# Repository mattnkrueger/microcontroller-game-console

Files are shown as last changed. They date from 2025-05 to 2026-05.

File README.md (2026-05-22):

# Micro-controller Gaming Console

### Description
Microcontroller gaming console featuring "Etch-E-Sketch" and pixel art applications. Custom 3D Printed model housing 64x64 LED panel driven by ESP32, and 12 peripheral inputs morintored by Arduino Uno. 

---

### Repository Tags
<div align="left">
  Uiowa
  Handwritten
  Arduino
  ESP
  ESP
  Pio
  Fusion360
  Bambu Studio
</div>

---

<p align="center">
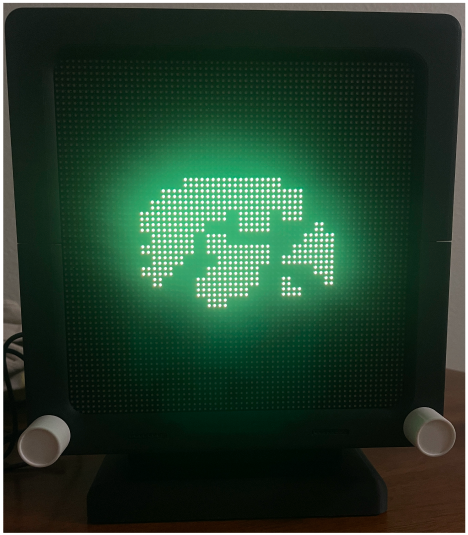
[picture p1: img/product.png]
display
  
</p>

Our project goal was to build something that wont be thrown away - or stripped down to preserve parts - after the class ends. The LED Matrix (and game system) sufficed; it allows for various programs, unique displays, and extendability beyond this course. Because of the ESP32, this system can be iterated on to support user I/O via a web application. However, that would be more of an IoT project than Embedded Systems... just our thinking. As we are roomates, this system is currently being held in our living room. The Hawkeye themed system compliments the room nicely haha.

Currently programmed is 'EtchASketch' and a Pixel Art image viewer. The 'EtchASketch' program is controlled by two dials attached to the front of the system. This works identically to the original game and extends it further with the RGB capability of the LED Matrix. To navigate colors, the user can press buttons on the side of the system (similar to a tv) to select wanted color.
The Pixel Art image has meticulously drawn pixel art images which can be cycled through using the navigation controls on the side of the system.

To navigate between programs, the home button (has home icon) can be clicked to bring up a navigation screen. 

To power off the system, the power button is held for 5 seconds. After which a simple click will return power to the system.

Overall, our project was - and is - predicated on simplicity and ease of use. As any good hardware and software, the design is built to last. The design is fun and accessible to all, which is a success in our books.

## Final Product
<p align="center">
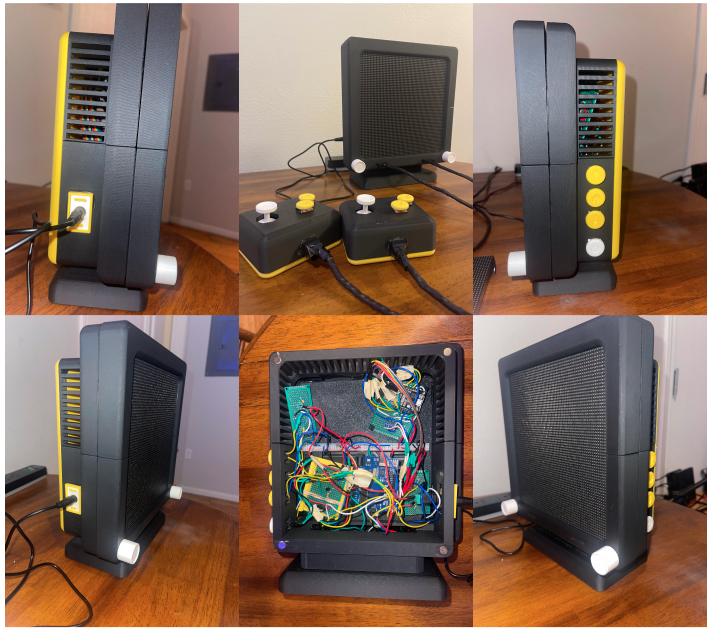
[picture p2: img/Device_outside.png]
Device Outside
  
</p>
<p align="center">
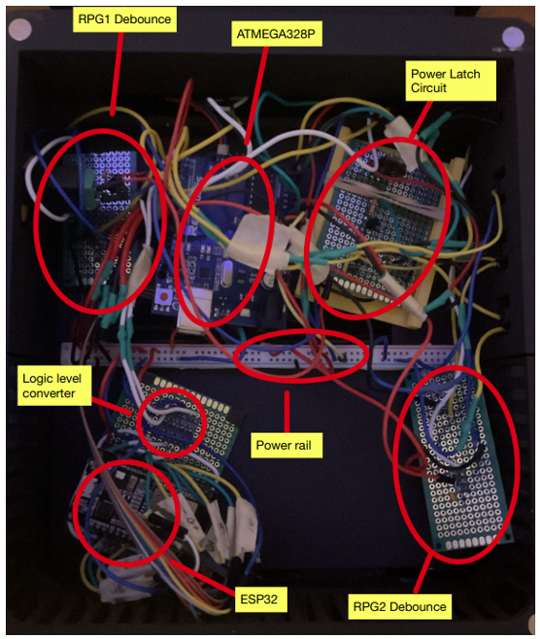
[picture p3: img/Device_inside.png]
Device Inside
  
</p>
<p align="center">
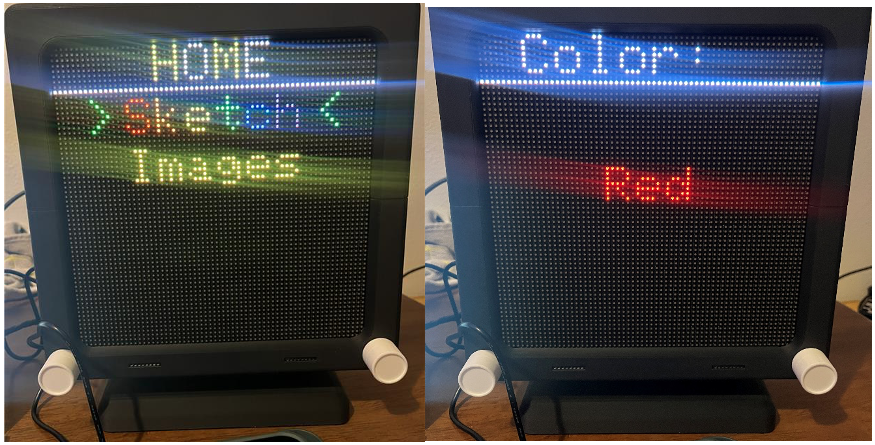
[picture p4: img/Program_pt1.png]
Program Part 1
  
</p>
<p align="center">
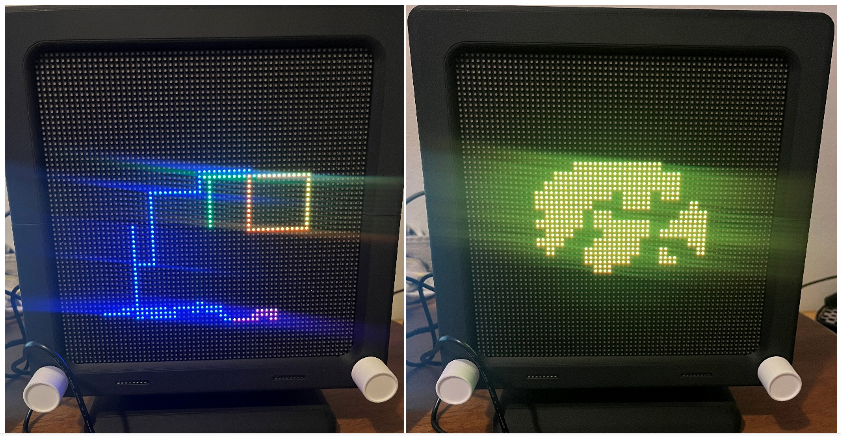
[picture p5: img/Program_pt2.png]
Program Part 2
  
</p>

## Schematic
<p align="center">
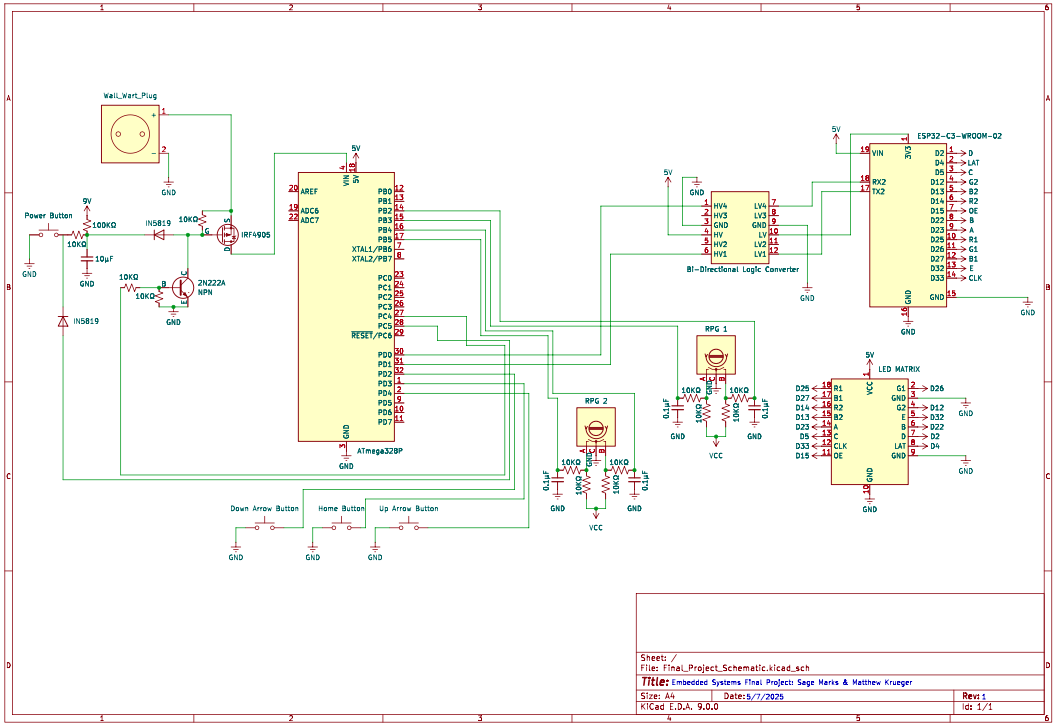
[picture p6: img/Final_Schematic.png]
KiCad Schematic
  
</p>

## Demo Video
[Download Project Demo Video](project_report/project_video.MOV)

## Parts List
THIS IS NOT AN EXHAUSTIVE LIST OF PARTS REQUIRED
Note this list does not include the cost of wires, adaptors, psu, etc. this is negligible and already on hand.
There are also various electrical components that were provided by the University of Iowa.

Here are the most relevant parts and their purpose, quantity, and cost
| Part | Description | Quantity | Unit Cost |
|---|---|---|---|
| ESP32 DevKitV1| Microcontroller to interface LED Matrix | 1 | $5 (off-brand)|
| 64x64 RGB LED Matrix Panel | LED Matrix for display| 1 | $29.99 (off-brand)|
| Arduino Uno | Microcontroller to handle user input | 1 | $0 (provided)
| 3D printed parts | Iowa themed, 3d enclosures | many | ~$12
| magnets | easy access to inside of enclosures | many | ~$5

Total sums to around ~$50+

## 3D Models
All parts were designed inside of Fusion360 and printed using a BambuLab P1S 3D-printer
[3D Models & Cost Breakdown](./3d_models/README.md)

<p align="center">
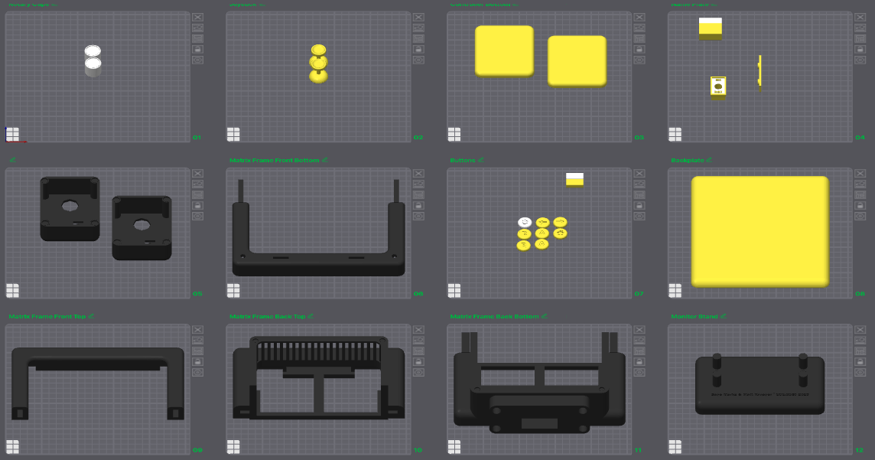
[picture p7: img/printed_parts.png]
3D Printed Parts
  
</p>

## Source Code
* [ATMega328P Source Code](./src/ATMega328P/README.md)
* [ESP32 Source Code](./src/ESP32/README.md)

## Authors

<div style="display: flex; justify-content: center; gap: 60px;">
  <div align="center">
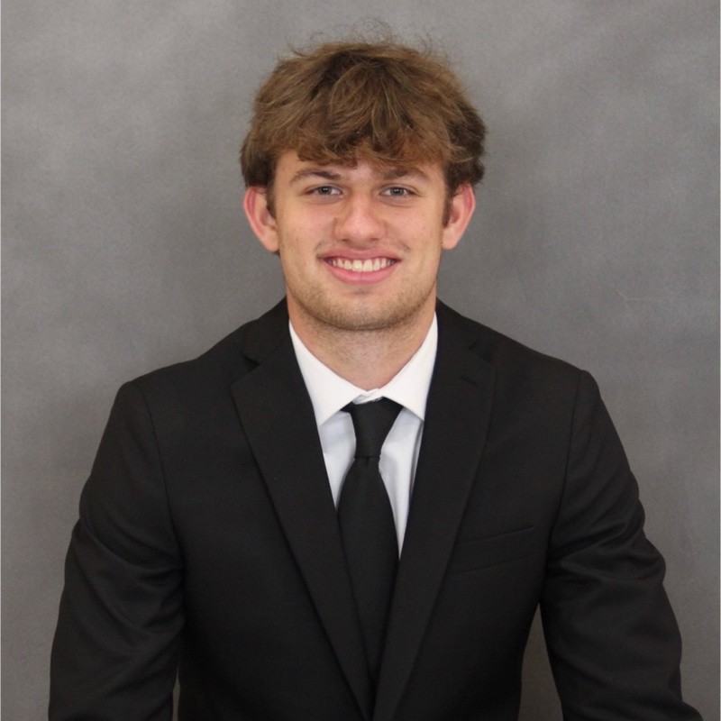
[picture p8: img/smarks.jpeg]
Sage Marks
    
    <div style="display: flex; align-items: center; justify-content: center;">
      Sage Marks
    </div>
    <div>
      <a href="mailto:sage-marks@uiowa.edu">Email</a> | <a href="https://www.linkedin.com/in/sage-marks-71a044293/">LinkedIn</a>
    </div>
  </div>

  <div align="center">
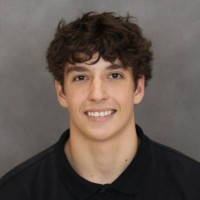
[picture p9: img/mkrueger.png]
Matt Krueger
    
    <div style="display: flex; align-items: center; justify-content: center;">
      Matt Krueger
    </div>
    <div>
      <a href="mailto:matthew-krueger@uiowa.edu">Email</a> | <a href="https://www.linkedin.com/in/mattnkrueger/">LinkedIn</a>
    </div>
  </div>
</div>

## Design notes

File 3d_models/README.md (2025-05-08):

# 3D Printed Parts
This project was made unique using 3D printed containers - embedding the system. These were designed on Fusion360 (thankfully free for students) and printed on a BambuLab P1S printer. Here is the final product:

## Parts List

### Enclosure Components
| Part Name | Description | STL File | Unit Cost | Quantity | Total |
|---|---|---|---|---|---|
| Controller Top | Main frame for holding controller components | [FINAL_controller_frame.stl](FINAL_controller_frame.stl) | $1.09 | 2 | $2.18 |
| Controller Bottom | Bottom plate for the controller enclosure | [FINAL_controller_bottom.stl](FINAL_controller_bottom.stl) | $0.665 | 2 | $1.33 |
| Controller Name Plate | Decorative name plate for the controller | [FINAL_controller_name_plate.stl](FINAL_controller_name_plate.stl) | $0.67 | 2 | $1.34 |
| LED Matrix Frame | Frame for holding LED matrix display | [FINAL_LED_Matrix_Frame.stl](FINAL_LED_Matrix_Frame.stl) | $5.31 | 1 | $5.31 |

### Input Controls
| Part Name | Description | STL File | Unit Cost | Quantity | Total |
|---|---|---|---|---|---|
| A Button | "A" action button for the controller | [FINAL_btn_A.stl](FINAL_btn_A.stl) | $0.02125 | 2 | $0.0425 |
| B Button | "B" action button for the controller | [FINAL_btn_B.stl](FINAL_btn_B.stl) | $0.02125 | 2 | $0.0425 |
| Arrow Button | Directional arrow button | [FINAL_btn_arrow.stl](FINAL_btn_arrow.stl) | $0.02125 | 2 | $0.0425 |
| Home Button | Home navigation button | [FINAL_btn_home.stl](FINAL_btn_home.stl) | $0.02125 | 1 | $0.02125 |
| Power Button | Power control button | [FINAL_btn_power.stl](FINAL_btn_power.stl) | $0.02125 | 1 | $0.02125 |
| Joystick Housing | Housing for joystick component | [FINAL_joystick.stl](FINAL_joystick.stl) | $0.095 | 2 | $0.19 |
| RPG Cap (2mm) | 2mm cap for rotary pulse generator | [FINAL_rpg_cap_2mm.stl](FINAL_rpg_cap_2mm.stl) | $0.08 | 2 | $0.16 |
| RPG Cap (Flush) | Flush cap for rotary pulse generator | [FINAL_rpg_cap_flush.stl](FINAL_rpg_cap_flush.stl) | $0.25 | 1 | $0.25 |
| Circular Button | 20mm circular action button | [FINAL_btn_circle_20mm.stl](FINAL_btn_circle_20mm.stl) | $0.02125 | 0 | $0.00 |

### Component Mounts
| Part Name | Description | STL File | Unit Cost | Quantity | Total |
|---|---|---|---|---|---|
| ESP32 Slider | Sliding mount for ESP32 microcontroller | [FINAL_ESP32_slider.stl](FINAL_ESP32_slider.stl) | $0.31 | 1 | $0.31 |
| Arduino Slider | Sliding mount for Arduino board | [FINAL_arduino_slider.stl](FINAL_arduino_slider.stl) | $0.30 | 1 | $0.30 |
| Controller Circuit Perfboard Slider | Sliding mount for controller perfboard circuit | [FINAL_controller_circuit_perfboard_slider.stl](FINAL_controller_circuit_perfboard_slider.stl) | $0.312 | 2 | $0.624 |
| Controller Pinout Perfboard Slider | Sliding mount for controller pinout perfboard | [FINAL_controller_pinout_perfboard_slider.stl](FINAL_controller_pinout_perfboard_slider.stl) | $0.16 | 2 | $0.32 |

## Cost Summary
total: **~$12.51**

### Breakdown by Category:
- Enclosure Components: $10.16
- Input Controls: $0.76
- Component Mounts: $1.55 

** note, we picked PLA Matte Black and PLA Matte Yellow for the filament of choice (and got deals on the rolls... this is not official cost, but a good estimate)

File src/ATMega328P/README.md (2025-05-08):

# ATMega328P Firmware for Embedded Etch-A-Sketch

## Overview
This firmware serves as an interface between user input devices and the ESP32, working as a dummy terminal. It captures physical inputs (buttons, rotary encoders, joysticks) and converts them into commands sent via UART to the ESP32 for processing.

## Hardware Components
- **Rotary Encoders**: Two RPGs (rotary pulse generators) for precise input
- **System Buttons**: Up/Down arrows and Home button
- **Controller Buttons**: Two controllers, each with A & B buttons
- **Joysticks**: Two analog joysticks (X & Y for each)
- **Power Button**: For system power control

## Communication
The ATMega328P communicates with the ESP32 via UART at 115200 baud.

## Key Features
- Interrupt-driven input detection for buttons and rotary encoders
- Debouncing for all button inputs
- Power management with press-and-hold functionality
- Home button with different actions for short and long press
- Joystick control with deadzone handling
- Controller enable/disable functionality based on system context

## PlatformIO Configuration
This is a PlatformIO project. The configuration file (`platformio.ini`) contains:

```
; PlatformIO Project Configuration File
;
;   Build options: build flags, source filter
;   Upload options: custom upload port, speed and extra flags
;   Library options: dependencies, extra library storages
;   Advanced options: extra scripting
;
; Please visit documentation for the other options and examples
; https://docs.platformio.org/page/projectconf.html

[env:ATmega328P]
platform = atmelavr
board = ATmega328P
framework = arduino

monitor_speed = 115200
```

## How to Run
1. Install [PlatformIO](https://platformio.org/) (available as extension for VS Code or standalone CLI)
2. Open the project folder
3. Build the project with `platformio run`
4. Upload to your ATMega328P with `platformio run --target upload`
5. Monitor serial output with `platformio device monitor`

Alternatively, you can use the simple Platformio interface to 

<p align="center">
  PlatformIO Interface
</p>

## Documentation

To view the [Doxygen](https://doxygen.nl/) generated documentation:

### Windows
1. Navigate to the `doxygenDocs/html` folder
2. Double-click `index.html` to open in your default web browser

### Mac
1. Navigate to the `doxygenDocs/html` folder
2. Double-click `index.html` to open in your default web browser
   ```bash
   open doxygenDocs/html/index.html
   ```

## Authors  

<div style="display: flex; justify-content: center; gap: 60px;">
  <div align="center">
    Sage Marks
    <div style="display: flex; align-items: center; justify-content: center;">
      Sage Marks
    </div>
    <div>
      <a href="mailto:sage-marks@uiowa.edu">Email</a> | <a href="https://www.linkedin.com/in/sage-marks-71a044293/">LinkedIn</a>
    </div>
  </div>

  <div align="center">
    Matt Krueger
    <div style="display: flex; align-items: center; justify-content: center;">
      Matt Krueger
    </div>
    <div>
      <a href="mailto:matthew-krueger@uiowa.edu">Email</a> | <a href="https://www.linkedin.com/in/mattnkrueger/">LinkedIn</a>
    </div>
  </div>
</div>

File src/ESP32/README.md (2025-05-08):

# ESP32 Firmware for Embedded Etch-A-Sketch

## Overview
This firmware powers the display component of the Embedded Etch-A-Sketch system. It receives commands via UART from the ATMega328P controller and displays interactive applications on an LED matrix. The ESP32 processes user input commands and manages the state machine for different applications.

## Hardware Components
- **ESP32 DOIT DEVKIT V1**: Main controller for the display system
- **64x64 RGB LED Matrix**: Connected via HUB75E interface for display
- **UART Connection**: Interface with ATMega328P for receiving user input

## Communication
The ESP32 communicates with the ATMega328P via UART at 115200 baud using Serial2 (pins 16 & 17).

## Key Features
- State machine architecture with multiple application screens
- Color selection interface with various preset colors
- Etch-A-Sketch drawing program with precise pixel control
- Pixel art viewer with navigation between images
- Home screen with menu navigation

## Command Protocol
The ESP32 receives the following commands from the ATMega328P:
- `btnUpArrow` / `btnDownArrow`: Navigate menus or change colors
- `btnHomeClick`: Select menu items
- `btnHomeHold`: Return to previous screen
- `rpg1CW` / `rpg1CCW`: Control X-axis movement in Etch-A-Sketch
- `rpg2CW` / `rpg2CCW`: Control Y-axis movement in Etch-A-Sketch

## Applications
- **Etch-A-Sketch**: Interactive drawing application that allows users to draw with different colors using the rotary encoders
- **Pixel Art**: Displays a slideshow of pixel art images with navigation controls

## Matrix Configuration
The firmware is configured for a 64x64 RGB LED matrix using the HUB75 interface with the following pinout:
```
             +----------+-----------+
row 1:       | R1 (25)  | G1  (26)  |
             +----------+-----------+
row 2:       | B1 (27)  | GND (gnd) |
             +----------+-----------+
row 3:       | R2 (14)  | G2  (12)  |
             +----------+-----------+
row 4:       | B2 (13)  | E   (32)  |
             +----------+-----------+
row 5:       | A (23)   | B   (22)  |
             +----------+-----------+
row 6:       | C (05)   | D   (02)  |
             +----------+-----------+
row 7:       | CLK (33) | LAT (04)  |
             +----------+-----------+
row 8        | OE (15)  | GND (gnd) |
             +----------+-----------+
```

## PlatformIO Configuration
This is a PlatformIO project. The configuration file (`platformio.ini`) contains:

```
; PlatformIO Project Configuration File
;
;   Build options: build flags, source filter
;   Upload options: custom upload port, speed and extra flags
;   Library options: dependencies, extra library storages
;   Advanced options: extra scripting
;
; Please visit documentation for the other options and examples
; https://docs.platformio.org/page/projectconf.html

[env:esp32doit-devkit-v1]
platform = espressif32
board = esp32doit-devkit-v1
framework = arduino
lib_deps =
    fastled/FastLED
    Wire
    adafruit/Adafruit GFX Library
    https://github.com/mrfaptastic/ESP32-HUB75-MatrixPanel-I2S-DMA.git

build_flags =
    -DUSE_GFX_ROOT

upload_speed = 460800           
monitor_speed = 115200
monitor_filters = esp32_exception_decoder
```

## How to Run
1. Install [PlatformIO](https://platformio.org/) (available as extension for VS Code or standalone CLI)
2. Open the project folder
3. Build the project with `platformio run`
4. Upload to your ESP32 with `platformio run --target upload`
5. Monitor serial output with `platformio device monitor`

Alternatively, you can use the PlatformIO interface within VS Code:

<p align="center">
  PlatformIO Interface
</p>

## Documentation

To view the [Doxygen](https://doxygen.nl/) generated documentation:

### Windows
1. Navigate to the `doxygenDocs/html` folder
2. Double-click `index.html` to open in your default web browser

### Mac
1. Navigate to the `doxygenDocs/html` folder
2. Double-click `index.html` to open in your default web browser
   ```bash
   open doxygenDocs/html/index.html
   ```

## Authors  

<div style="display: flex; justify-content: center; gap: 60px;">
  <div align="center">
    Sage Marks
    <div style="display: flex; align-items: center; justify-content: center;">
      Sage Marks
    </div>
    <div>
      <a href="mailto:sage-marks@uiowa.edu">Email</a> | <a href="https://www.linkedin.com/in/sage-marks-71a044293/">LinkedIn</a>
    </div>
  </div>

  <div align="center">
    Matt Krueger
    <div style="display: flex; align-items: center; justify-content: center;">
      Matt Krueger
    </div>
    <div>
      <a href="mailto:matthew-krueger@uiowa.edu">Email</a> | <a href="https://www.linkedin.com/in/mattnkrueger/">LinkedIn</a>
    </div>
  </div>
</div>

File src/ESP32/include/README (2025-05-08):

# Source Headers
Currently supported programs (@ time of submission of Embedded Systems Final Project ('Embedded EtchASketch') )

### Etch A Sketch: 
- ColorSelectScreen.h: landing page for EtchASketch program, giving user options for colors to begin drawing with
- EtchASketch.h: program driver for EtchASketch program. User action from Arduino over UART deciphered and mapped to action in program.

### Pixel Art
- PixelArt.h: program driver for Pixel Art slideshow image viewer.

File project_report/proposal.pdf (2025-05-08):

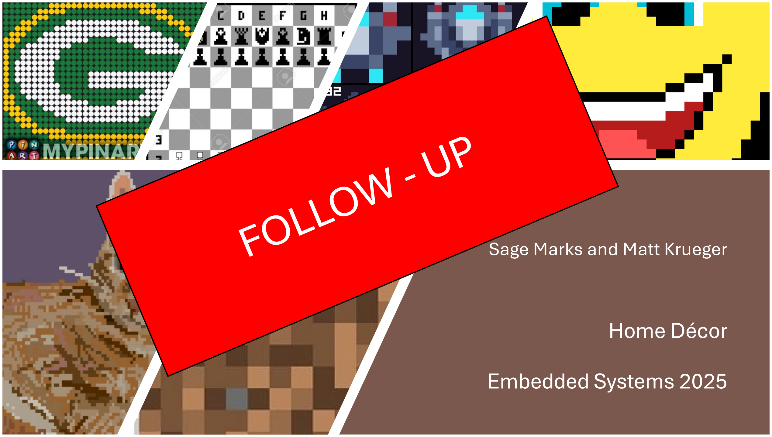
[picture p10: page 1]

# Home Décor

# Embedded Systems 2025

# FOLLOW

# Sage Marks and Matt Krueger

- UP

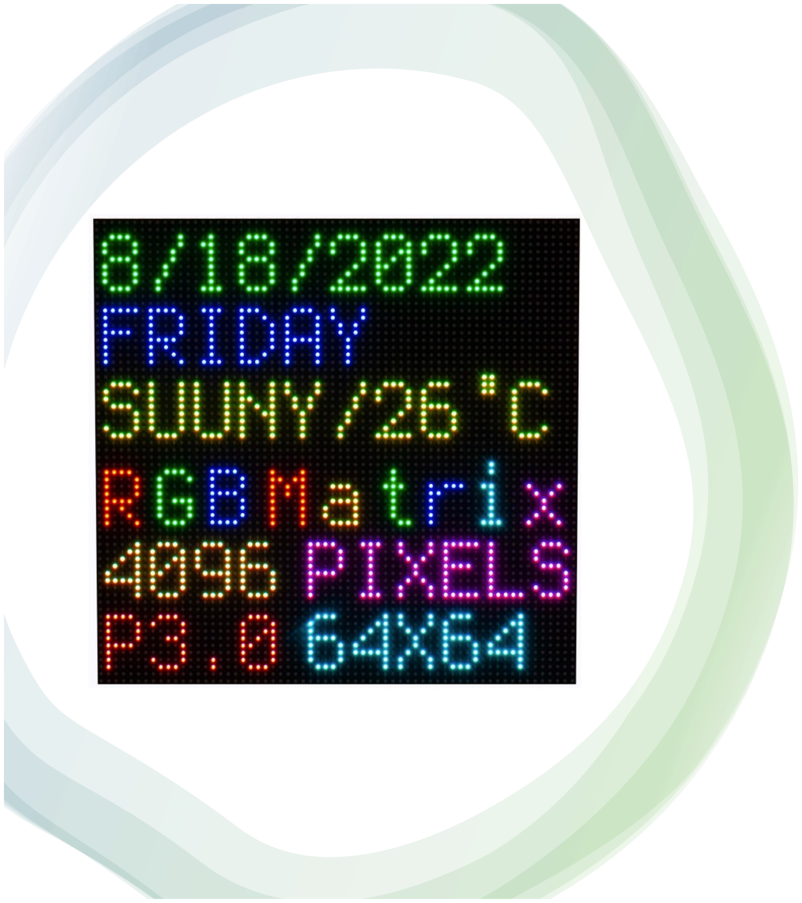
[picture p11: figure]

# Issues: Address Space of Uno

- Problem: memory size of ATmega328p
- ATmega328P has 2KB SRAM whilst there are 4096 addresses on the LED matrix (64^2). Ultimately, the ATmega328p is NOT COMPATIBLE with any 64x64 led matrix due to its limited address space.
- Solution: use adequate microcontroller
- An easy alternative (and a microcontroller that we have on hand already) is the ESP32. The ESP-Wroom-32 has 512MB of RAM, which can access the 4096 led addresses in the matrix… and more.

ESP-32 Specs: • Datasheet: ESP-WROOM-32 (https://www.espressif.com/sites/default/files/documentation/esp32-wroom-32_datasheet_en.pdf)

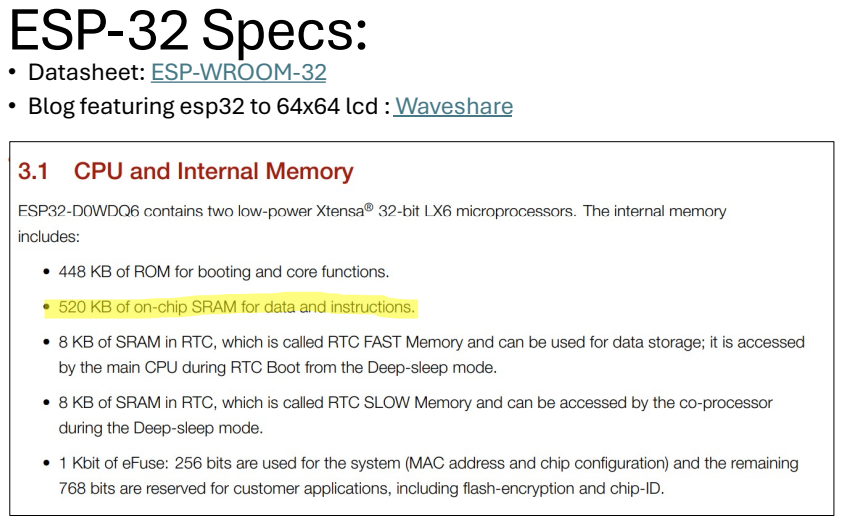
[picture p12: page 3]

• Blog featuring esp32 to 64x64 lcd : Waveshare (https://www.waveshare.com/wiki/RGB-Matrix-P3-64x64)

# Compromise

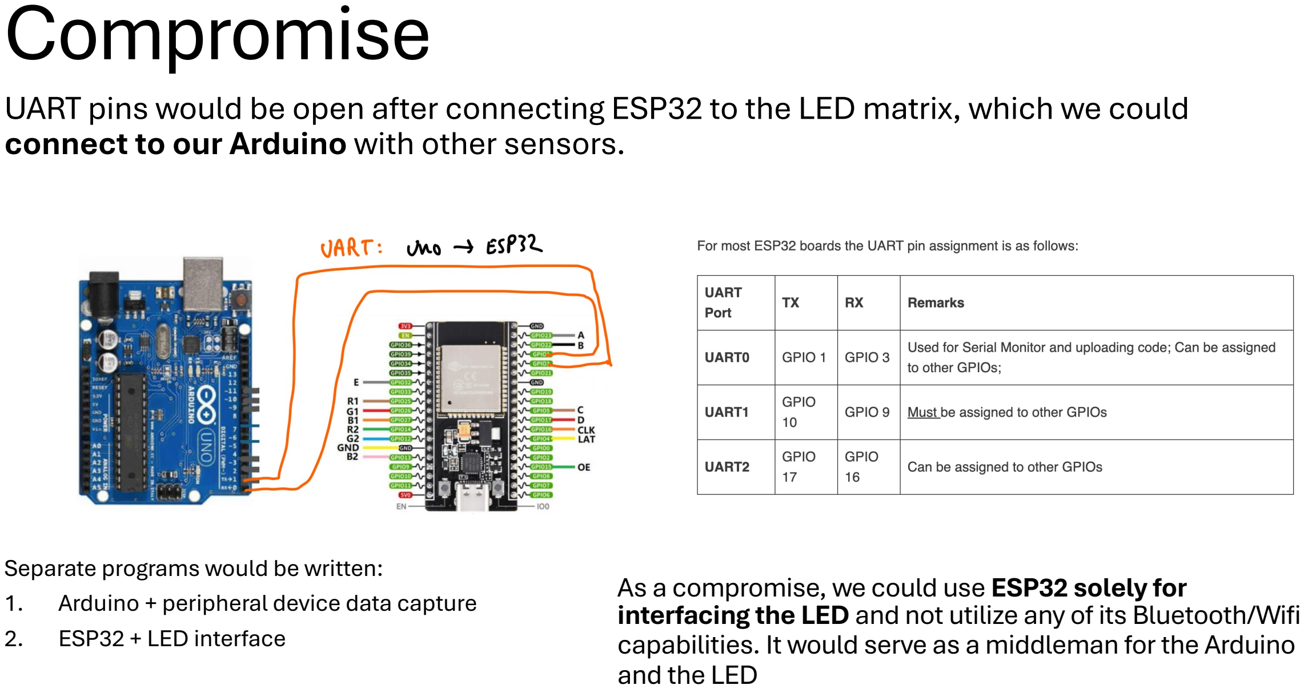
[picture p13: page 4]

## UART pins would be open after connecting ESP32 to the LED matrix, which we could

connect to our Arduino with other sensors.

### Separate programs would be written: 1. Arduino + peripheral device data capture 2. ESP32 + LED interface

## As a compromise, we could use ESP32 solely for interfacing the LED and not utilize any of its Bluetooth/Wifi capabilities. It would serve as a middleman for the Arduino and the LED

# High Level Workflow

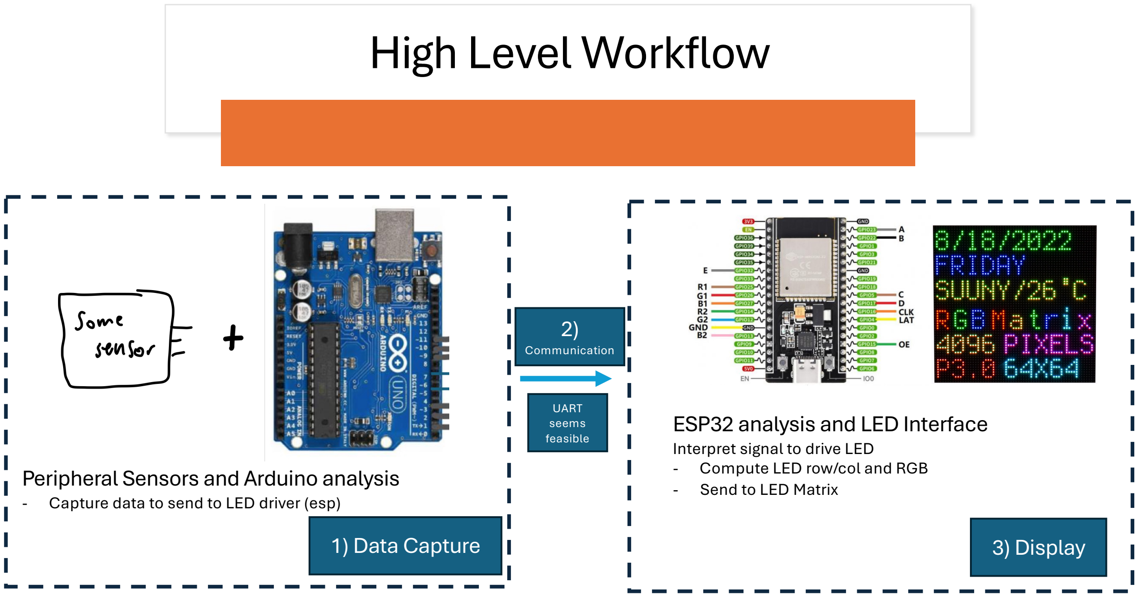
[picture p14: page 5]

## Peripheral Sensors and Arduino analysis - Capture data to send to LED driver (esp)

## ESP32 analysis and LED Interface

Interpret signal to drive LED
- Compute LED row/col and RGB
- Send to LED Matrix
1) Data Capture | 2) Display 3) Display

UART
seems
feasible

2)

Communication

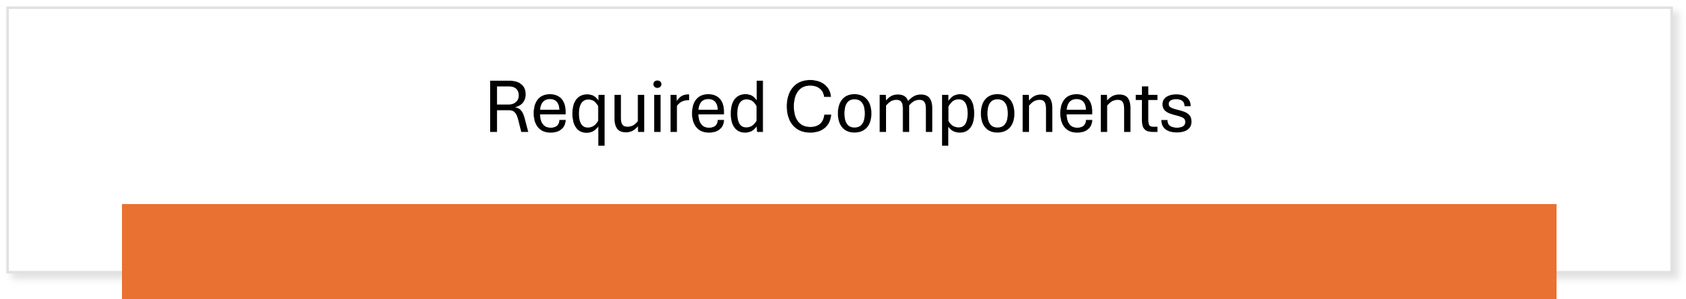
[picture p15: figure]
Required Components

Component | Amount Required | Usage | Do we have?
ESP32 | 1 | LED Matrix Interface | YES
64x64 LED Matrix | 1 | Display sensor data | YES
Arduino UNO | 1 | Capture sensor data | YES
Sensor | TBD | TBD | TBD

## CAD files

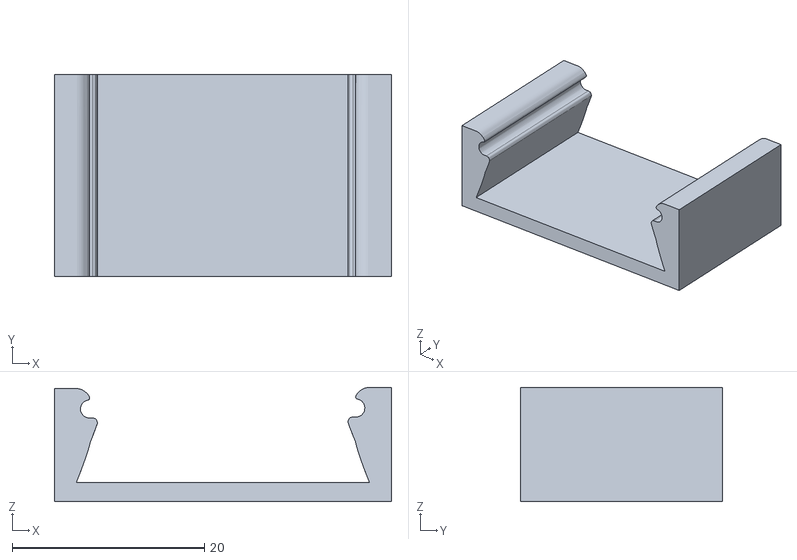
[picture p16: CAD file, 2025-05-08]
3d_models/FINAL_controller_pinout_perfboard_slider.stl
35.0 x 21.0 x 11.8

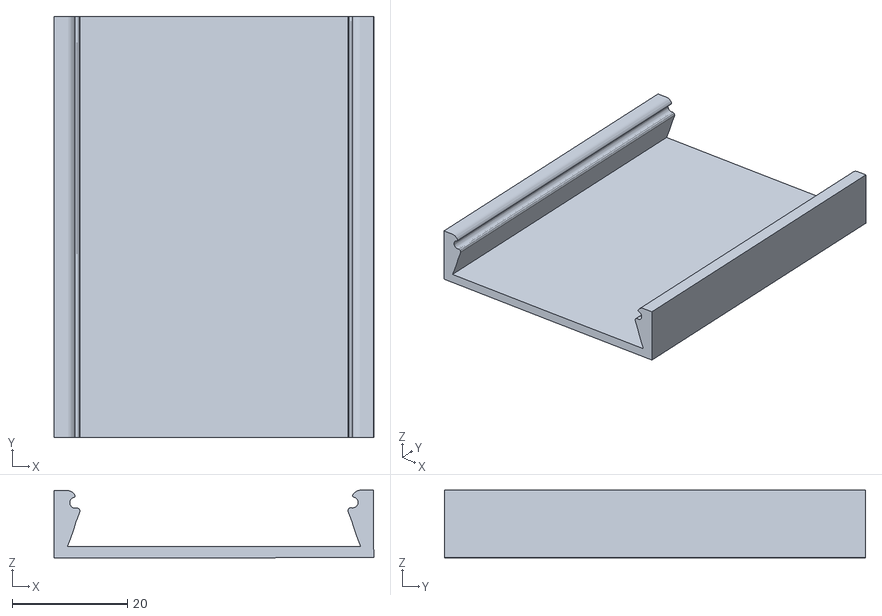
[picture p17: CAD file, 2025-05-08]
3d_models/FINAL_ESP32_slider.stl
55.4 x 73.0 x 11.8

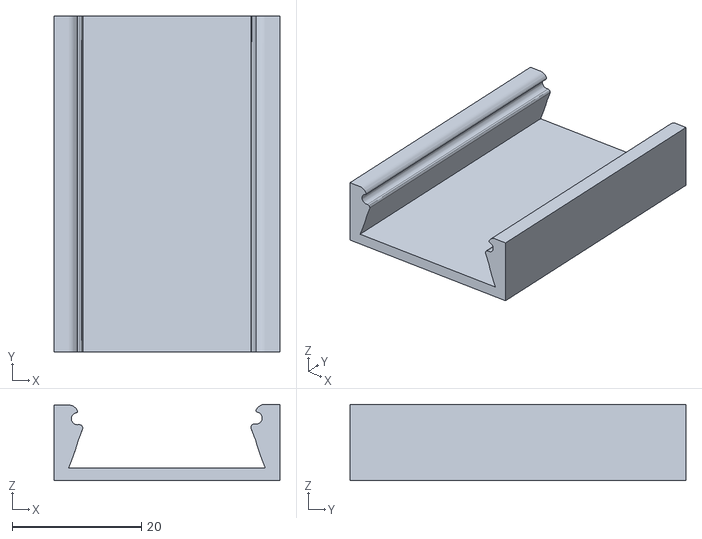
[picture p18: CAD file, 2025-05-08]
3d_models/FINAL_controller_circuit_perfboard_slider.stl
35.0 x 52.0 x 11.8

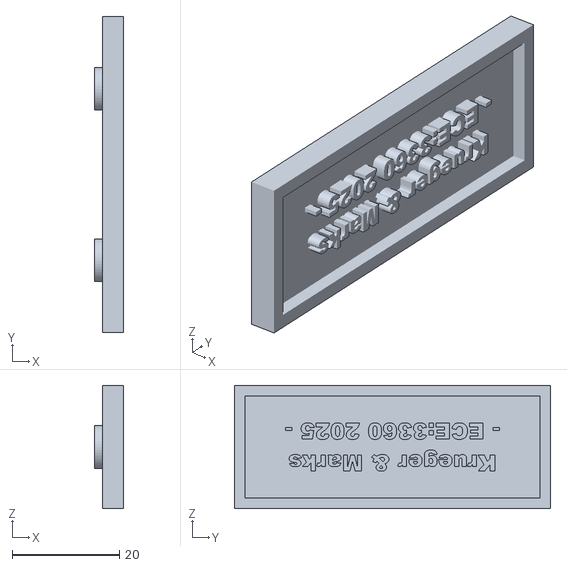
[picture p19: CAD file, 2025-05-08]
3d_models/FINAL_controller_name_plate.stl
5.50 x 59.0 x 23.0

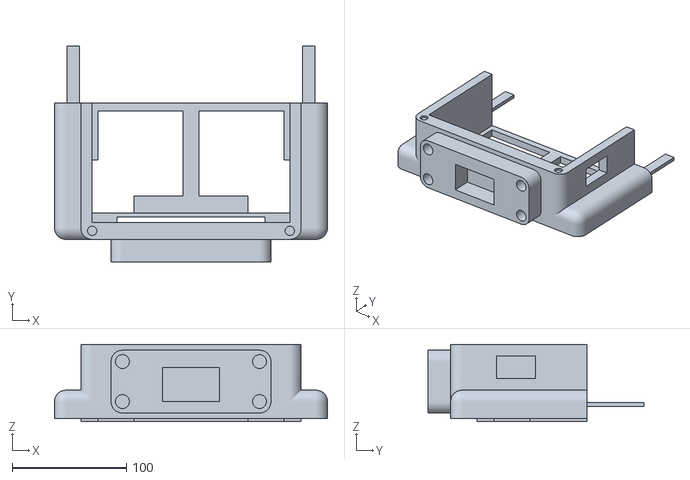
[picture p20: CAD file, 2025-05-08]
3d_models/FINAL_bottom_frame.stl
239.0 x 189.5 x 67.5

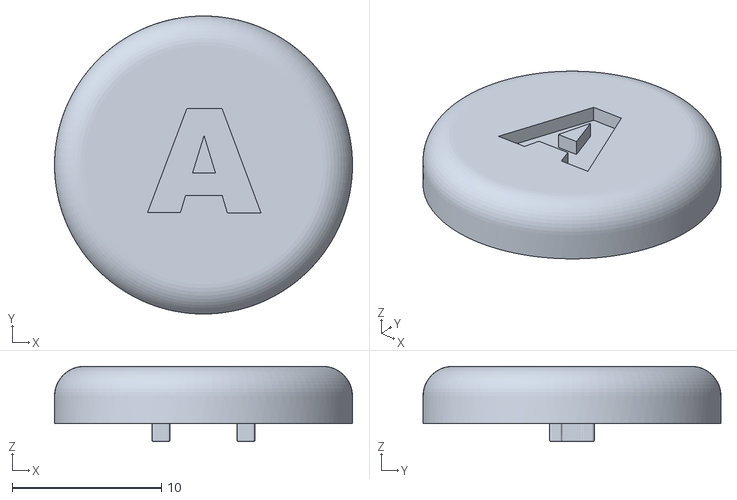
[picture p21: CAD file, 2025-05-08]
3d_models/FINAL_btn_A.stl
20.0 x 20.0 x 5.06

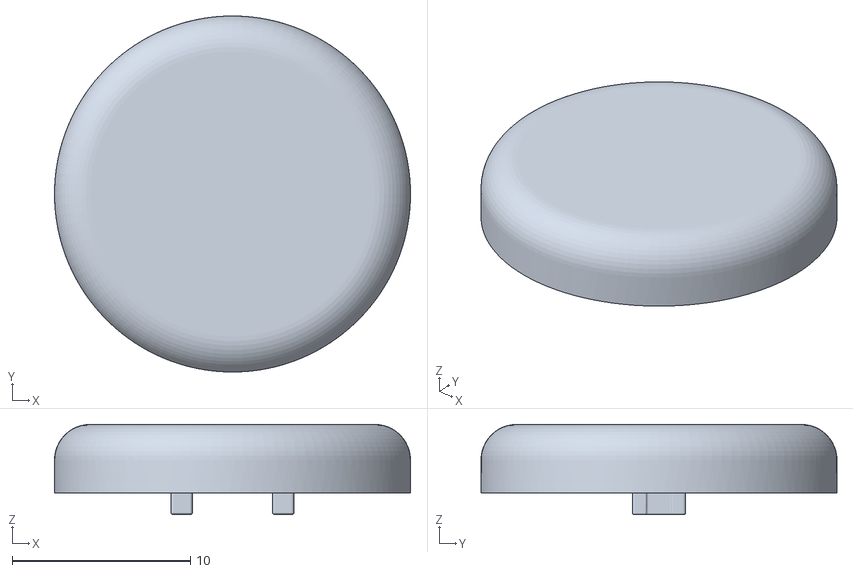
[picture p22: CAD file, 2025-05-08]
3d_models/FINAL_btn_circle_20mm.stl
20.0 x 20.0 x 5.06

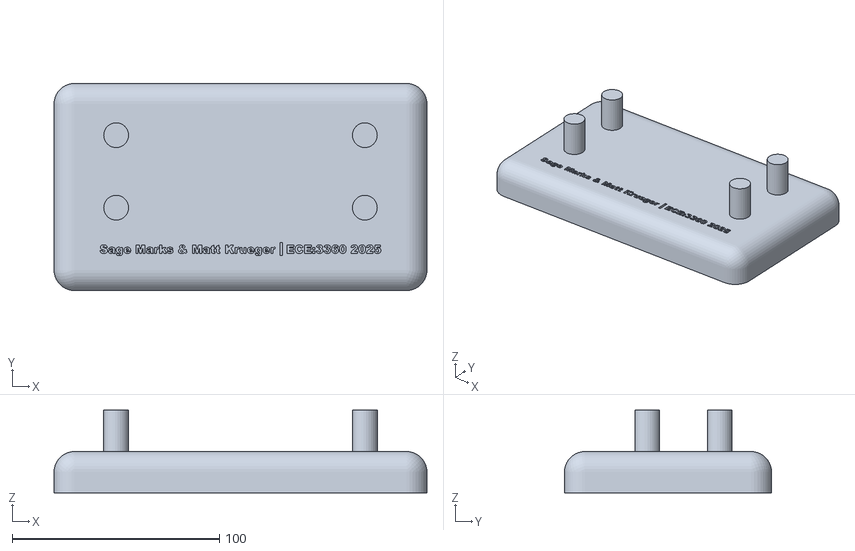
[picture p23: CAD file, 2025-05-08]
3d_models/FINAL_Monitor_Stand.stl
180.0 x 100.0 x 40.0

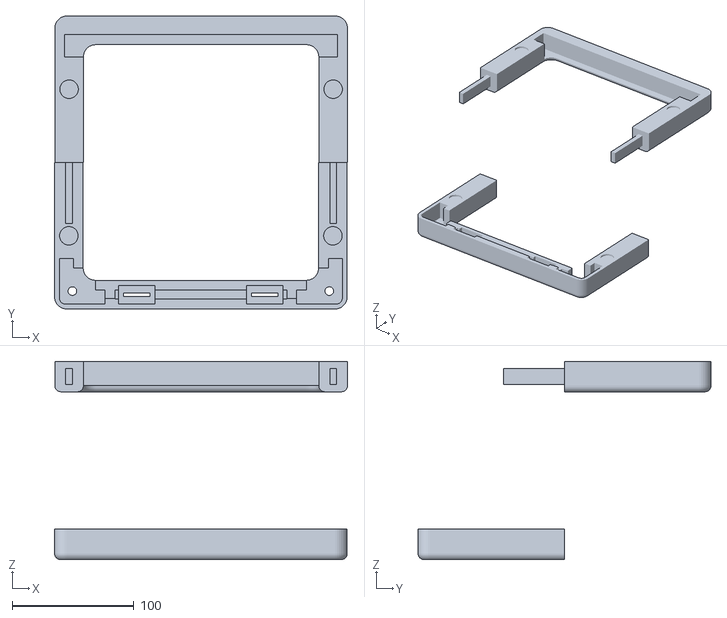
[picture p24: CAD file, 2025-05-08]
3d_models/FINAL_SplitBody_Matrix_Frame.stl
240.2 x 240.2 x 162.6

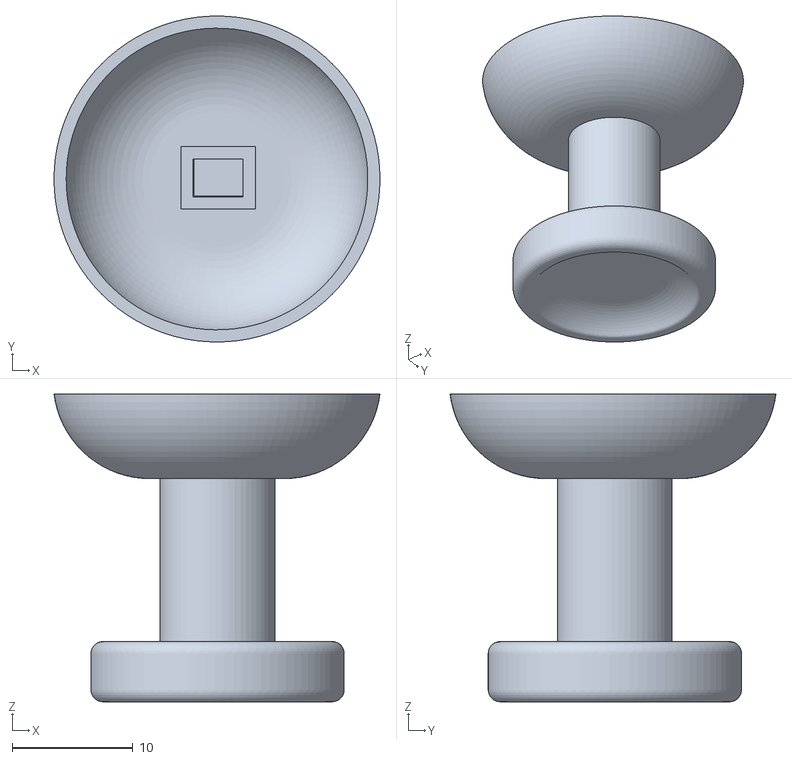
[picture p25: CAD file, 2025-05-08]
3d_models/FINAL_joystick.stl
27.0 x 27.0 x 25.5

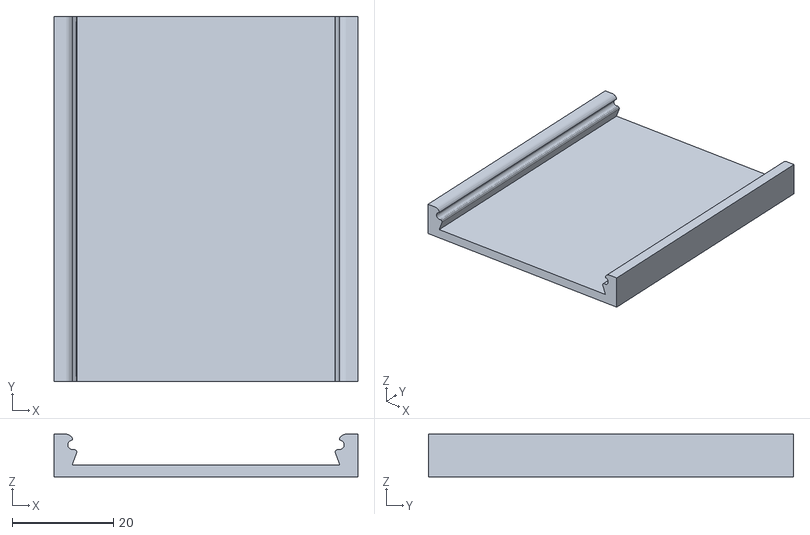
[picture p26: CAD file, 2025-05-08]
3d_models/FINAL_arduino_slider.stl
59.9 x 72.0 x 8.43

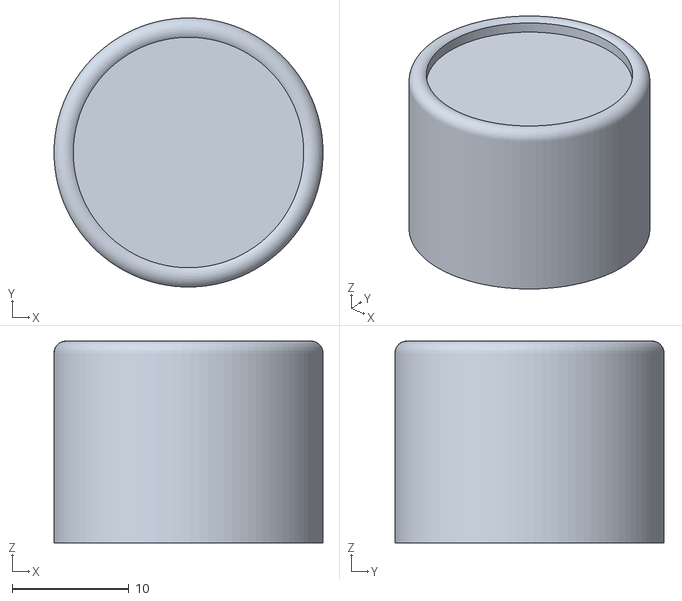
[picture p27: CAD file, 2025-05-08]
3d_models/FINAL_rpg_cap_flush.stl
23.0 x 23.0 x 17.2

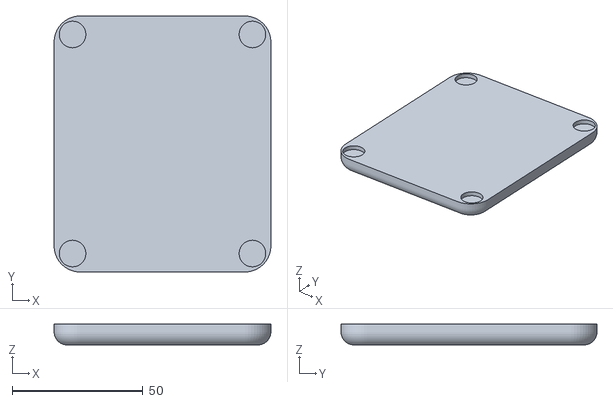
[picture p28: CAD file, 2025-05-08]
3d_models/FINAL_controller_bottom.stl
83.0 x 98.0 x 8.00

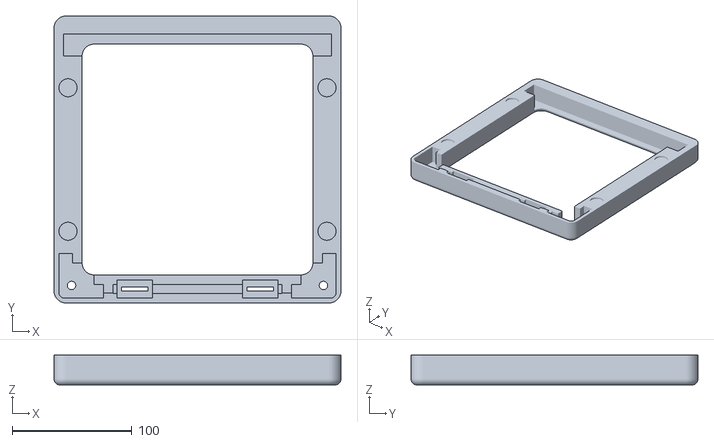
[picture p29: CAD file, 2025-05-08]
3d_models/FINAL_LED_Matrix_Frame.stl
240.0 x 240.0 x 25.0

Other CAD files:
3d_models/FINAL_btn_B.stl
3d_models/FINAL_btn_arrow.stl
3d_models/FINAL_inside_plate.stl
3d_models/FINAL_btn_home.stl
3d_models/FINAL_btn_power.stl
3d_models/FINAL_controller_top.stl
3d_models/FINAL_rpg_cap_2mm.stl

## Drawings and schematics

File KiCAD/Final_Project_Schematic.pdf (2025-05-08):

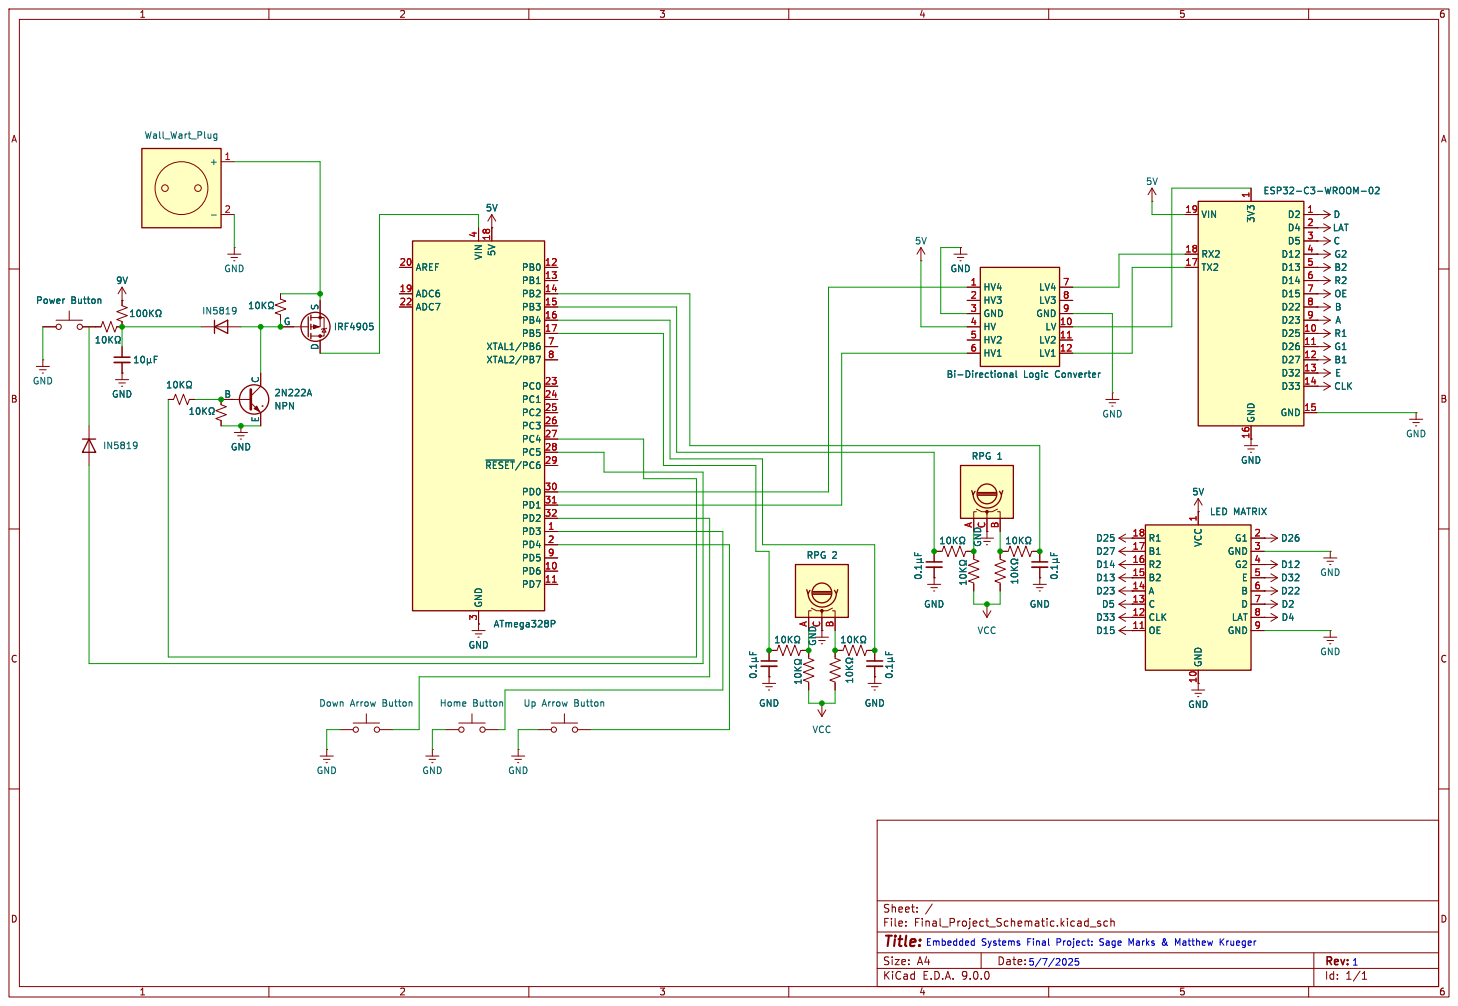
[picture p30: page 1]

5V Down Arrow Button GND

LAT GND þÿ0.1µF þÿ10K©

B GND þÿ10K© þÿ0.1µFþÿ10K© GND þÿ10K© þÿ10K© þÿ0.1µF þÿ10K© GND

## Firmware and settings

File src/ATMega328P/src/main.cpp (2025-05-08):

/**
 * @file main.cpp
 * @author Matt Krueger & Sage Marks
 * @brief Arduino Sketch for Embedded Systems Final Project
 * @version 0.2
 * @date 2025-05-03
 * 
 * @copyright Copyright (c) 2025
 * 
 * Included in this file is all I/O Pin definitions, methods, ISRs, and UART communication with the ESP32.
 * The functionality of the Arduino is simply a dummy terminal - converting actions made by the user (button click, rpg turn, joystick flick, etc) 
 * into a command that can be mapped to a function. This is sent over the UART channel to the ESP32 for processing.
 * 
 * No internal libraries were included and no external libraries were used. All functionality extended from Arduino AVR C built-in libraries
 * 
 */

 #include <Arduino.h>
 #include <avr/io.h>
 #include <avr/interrupt.h>
 
 //////////////////////////////////////////////////////////////////////////////////////////////////////////
 // ------------------------------------------ HARDWIRED PINS ------------------------------------------ //
 //////////////////////////////////////////////////////////////////////////////////////////////////////////
 // RPG Definitions 
 const uint8_t RPG2_B = 13;              // PB5      
 const uint8_t RPG2_A = 12;              // PB4
 const uint8_t RPG1_B = 11;              // PB3
 const uint8_t RPG1_A = 10;              // PB2
 
 // System Buttons
 const uint8_t BTN_UP_ARROW   = 4;       // PD4
 const uint8_t BTN_HOME       = 3;       // PD3
 const uint8_t BTN_DOWN_ARROW = 2;       // PD2
 
 // Controller Buttons
 const uint8_t BTN_CTRL_1A = 9;          // PB1
 const uint8_t BTN_CTRL_1B = 8;          // PB0
 const uint8_t BTN_CTRL_2A = 7;          // PD7
 const uint8_t BTN_CTRL_2B = 6;          // PD6
 
 // Controller Joysticks (analog)
 const uint8_t JOYSTICK_1X = A0;         // A0
 const uint8_t JOYSTICK_1Y = A1;         // A1
 const uint8_t JOYSTICK_2X = A2;         // A2
 const uint8_t JOYSTICK_2Y = A3;         // A3
 
 // Power Button pins 
 const uint8_t POWER_PIN  = A4;          // PC4 (A4)
 const uint8_t BTN_POWER = A5;           // PC5 (A5)
 
 ////////////////////////////////////////////////////////////////////////////////////////////////////////////
 // ------------------------------------------ Global Variables ------------------------------------------ //
 ////////////////////////////////////////////////////////////////////////////////////////////////////////////
 // store previous pinchanges 
 volatile uint8_t prevStateB = 0;
 volatile uint8_t prevStateC = 0;
 volatile uint8_t prevStateD = 0;
 
 // rpg changes
 volatile uint8_t prevRPG1A = 0;
 volatile uint8_t prevRPG1B = 0;
 volatile uint8_t prevRPG2A = 0;
 volatile uint8_t prevRPG2B = 0;
 
 // dirty and data flags 
 volatile uint8_t portB_flags = 0;
 volatile bool portB_dirty = false;
 volatile uint8_t portD_flags = 0;
 volatile bool portD_dirty = false;
 
 // status of the system
 volatile bool powerON = true;
 
 volatile bool prevHomeBTN = false;
 
 // status of controllers. This is depending on the current context of the system. Controllers enabled for Chess
 volatile bool controller1Enabled = false;
 volatile bool controller2Enabled = false;
 
 bool prevHomeState = HIGH;
 unsigned long homeStartPress = 0;
 
 /////////////////////////////////////////////////////////////////////////////////////////////////////////
 // ------------------------------------------ Button Timing ------------------------------------------ //
 /////////////////////////////////////////////////////////////////////////////////////////////////////////
 // debouncing for the buttons
 const int DEBOUNCE_MS = 50;
 const int HOLD_TIME_MS = 1000;                // hold timing timing for power & home button
 const int MIN_ON_TIME_MS = 2000; 
 
 // Global variables for power management
 volatile bool power_state = true;
 volatile uint32_t hold_counter = 0;
 volatile bool button_was_pressed = false;
 volatile unsigned long power_button_press_start = 0;
 
 ///////////////////////////////////////////////////////////////////////////////////////////////////////////////////////
 // ------------------------------------------ Interrupts Service Routines ------------------------------------------ //
 ///////////////////////////////////////////////////////////////////////////////////////////////////////////////////////
 
 /**
  * @brief Construct a new ISR object for PCINT[0..7] (port b)
  * 
  * PCINT0 (PB0): BTN_CONTROLLER_1B
  * PCINT1 (PB1): BTN_CONTROLLER_1A
  * PCINT2 (PB2): RPG_1A
  * PCINT3 (PB3): RPG_1B
  * PCINT4 (PB4): RPG_2A
  * PCINT5 (PB5): RPG_2B
  * PCINT6: none
  * PCINT7: none
  * 
  * Because these are pin changes and we have buttons, the interrupt will be called twice for all buttons - which is not ideal.
  * To combat this, we track the previous state of the pins and mask each button.
  * If there is a change then we update the current state to reflect this.
  * The entire current state of pin is then sent over UART
  * 
  * Yes, this is not a 'short' ISR, but as we have all GPIO pins attached it is necessary that the ISR is more involved
  * 
  */
 ISR(PCINT0_vect) {
   uint8_t pinB                = PINB;         // all pins to be masked below...
 
   bool isController1BClicked  = false;
   bool isController1AClicked  = false;
   bool isRPG1Clockwise        = false;
   bool isRPG1CounterClockwise = false;
   bool isRPG2Clockwise        = false;
   bool isRPG2CounterClockwise = false;
 
   // check controller 1 B
   if ((prevStateB & (1 << PB0)) && !(pinB & (1 << PB0))) {
     _delay_ms(DEBOUNCE_MS);
 
     pinB = PINB;
     if ((prevStateB & (1 << PB0)) && !(pinB & (1 << PB0))) {
       isController1BClicked = true;
     }
   }
 
   // check controller 1 A
   if ((prevStateB & (1 << PB1)) && !(pinB & (1 << PB1))) {
     _delay_ms(DEBOUNCE_MS);
     
     pinB = PINB;
     if ((prevStateB & (1 << PB1)) && !(pinB & (1 << PB1))) {
       isController1AClicked = true;
     }
   }
 
    // check RPG 1                                                                        here we perform a similar process to our Lab5, combining both A and B.
    uint8_t currRPG1A = (pinB & (1 << PB2)) ? 1 : 0;                                   // We shift left by one to make space for rpg1b.
    uint8_t currRPG1B = (pinB & (1 << PB3)) ? 1 : 0;                                   // Then we combine this with the previous & use codes to determine the rotation.
    uint8_t currRPG1       = (currRPG1A << 1) | currRPG1B;                             // now a 2 bit AB 00, 01, 10, 11 value
    uint8_t transitionRPG1 = (prevRPG1A << 3) | (prevRPG1B << 2) | (currRPG1);         // now a 4 bit ABAB value, with cases below
  
    switch (transitionRPG1) {
      case 0b0001: case 0b0111: case 0b1110: case 0b1000:
        // Clockwise
        isRPG1Clockwise = true;
        break;
      case 0b0010: case 0b0100: case 0b1101: case 0b1011:
        // Counter-clockwise
        isRPG1CounterClockwise = true;
        break;
      default:
        // on detent; ignore
        break;
    }
 
    prevRPG1A = currRPG1A; 
    prevRPG1B = currRPG1B;
 
    // check RPG 2                                                                        here we perform a similar process to our Lab5, combining both A and B.
    uint8_t currRPG2A = (pinB & (1 << PB5)) ? 1 : 0;                                   // We shift left by one to make space for rpg1b.
    uint8_t currRPG2B = (pinB & (1 << PB4)) ? 1 : 0;                                   // Then we combine this with the previous & use codes to determine the rotation.
    uint8_t currRPG2       = (currRPG2A << 1) | currRPG2B;                             // now a 2 bit AB 00, 01, 10, 11 value
    uint8_t transitionRPG2 = (prevRPG2A << 3) | (prevRPG2B << 2) | (currRPG2);         // now a 4 bit ABAB value, with cases below
  
    switch (transitionRPG2) {
      case 0b0001: case 0b0111: case 0b1110: case 0b1000:
        // Clockwise
        isRPG2Clockwise = true;
        break;
      case 0b0010: case 0b0100: case 0b1101: case 0b1011:
        // Counter-clockwise
        isRPG2CounterClockwise = true;
        break;
      default:
        // on detent; ignore
        break;
    }
 
    prevRPG2A = currRPG2A; 
    prevRPG2B = currRPG2B;
 
    // now, we build the flags to send over UART                                 Flags       
    uint8_t flags = 0;                                                         
    flags |= isController1BClicked << 0;                                       // b0: controller 1 'B'
    flags |= isController1AClicked << 1;                                       // b1: controller 1 'A'
    flags |= isRPG1Clockwise << 2;                                             // b2: RPG1 cw
    flags |= isRPG1CounterClockwise << 3;                                      // b3: RPG1 ccw (these are mutually exclusive)
    flags |= isRPG2Clockwise << 4;                                             // b4: RPG2 cw
    flags |= isRPG2CounterClockwise << 5;                                      // b5: RPG2 ccw (again, these are mutually exclusive)
    flags |= (0 << 6) | ( 0 << 7);                                             // b6,7: 0
 
    // update flags and set dirty if there was an action
    if (flags != 0) { 
     portB_flags = flags;
     portB_dirty = true;
    }
 
    prevStateB = pinB;
 }
 
 /**
  * @brief Construct a new ISR object for PCINT[16..23] (port d)
  * 
  * PCINT16 (PD0): none (uart rx)
  * PCINT17 (PD1): none (uart tx)
  * PCINT18 (PD2): BTN_DOWN_ARROW
  * PCINT19 (PD3): none
  * PCINT20 (PD4): BTN_UP_ARROW
  * PCINT21 (PD5): none 
  * PCINT22 (PD6): BTN_CTRL_2B
  * PCINT23 (PD7): BTN_CTRL_2A
  * 
  */
 ISR(PCINT2_vect) {
   uint8_t pinD = PIND;        // all pins to be masked below...
 
   // boolean values to build a payload for message
   bool isDownArrowClicked      = false;
   bool isUpArrowClicked        = false;
   bool isController2BClicked   = false;
   bool isController2AClicked   = false;
 
   // check down arrow
   if ((prevStateD & (1 << PD2)) && !(pinD & (1 << PD2))) {
     _delay_ms(DEBOUNCE_MS);
 
     pinD = PIND;
     if ((prevStateD & (1 << PD2)) && !(pinD & (1 << PD2))) {
       isDownArrowClicked = true;
     }
   }
 
   // check up arrow 
   if ((prevStateD & (1 << PD4)) && !(pinD & (1 << PD4))) {
     _delay_ms(DEBOUNCE_MS);
 
     pinD = PIND;
     if ((prevStateD & (1 << PD4)) && !(pinD & (1 << PD4))) {
       isUpArrowClicked = true;
     }
   }
 
   // check controller 2 B
   if ((prevStateD & (1 << PD6)) && !(pinD & (1 << PD6))) {
     _delay_ms(DEBOUNCE_MS);
 
     pinD = PIND;
     if ((prevStateD & (1 << PD6)) && !(pinD & (1 << PD6))) {
       isController2BClicked = true;
     }
   }
 
   // check controller 2 A
   if ((prevStateD & (1 << PD7)) && !(pinD & (1 << PD7))) {
     _delay_ms(DEBOUNCE_MS);
 
     pinD = PIND;
     if ((prevStateD & (1 << PD7)) && !(pinD & (1 << PD7))) {
       isController2AClicked = true;
     }
   }
 
   // now, we build the flags to send over UART                                 Flags       
   uint8_t flags = 0;                                                           // b0: none 
   flags |= (0 << 0) | (0 << 1);                                                // b1: none
   flags |= isDownArrowClicked << 2;                                            // b2: down arrow clicked
   flags |= (0 << 3);                                                           // b3: home clicked
   flags |= isUpArrowClicked << 4;                                              // b4: up arrow clicked 
   flags |= (0 << 5);                                                           // b5: none
   flags |= isController2BClicked << 6;                                         // b6: controller 'B' clicked
   flags |= isController2AClicked << 7;                                         // b7: controller 'A' clicked
 
   // update flags and set dirty if there was an action
   if (flags != 0) {
     portD_flags = flags;
     portD_dirty = true;
   }
 
   prevStateD = pinD;
 }
 
 /**
  * @brief enable pin change interrupts
  * 
  * enable PCINT for ALL buttons connected to the Arduino
  * 
  */
 void enableButtonInterrupts() {
   PCICR  |= (1 << PCIE0) | (1 << PCIE1) | (1 << PCIE2);  // turn on pcint for b, c, and d ports
   PCMSK0 |= 0b00111111;                                  // PCINT[0..5] (port b)
   PCMSK1 |= 0x00;                                        // NONE of pinchange 1 (port C)
   PCMSK2 |= 0xFF;                                        // ALL portd PCINT[16..23] (port d)
 }
 
 ////////////////////////////////////////////////////////////////////////////////////////////////////////
 // ------------------------------------------ Power Button ------------------------------------------ //
 ////////////////////////////////////////////////////////////////////////////////////////////////////////
 
 /**
  * @brief handle safe power toggling
  * 
  * We are limited to using polling for multifunctionality buttons as we cannot check for a press and hold inside of interrupt.
  *
  * programmed for two signals: 
  * 1. press > 1 second ---> turn off
  * 2. press < 1 second ---> turn on 
  * 
  */

  /**
  * @brief handle power button
  * 
  * Implements power control logic from the second code sample
  * Uses debouncing, hold detection, and power state management
  */
 void checkPowerBTN(void) {
  // Read button state (active LOW)
  bool buttonPressed = (digitalRead(BTN_POWER) == LOW);
  
  if (buttonPressed) {
    // Debounce
    delay(DEBOUNCE_MS);
    buttonPressed = (digitalRead(BTN_POWER) == LOW);
    
    if (buttonPressed) {
      // Confirmed press
      if (!button_was_pressed) {
        button_was_pressed = true;
        power_button_press_start = millis();
      }
      
      // Calculate hold time
      unsigned long hold_time = millis() - power_button_press_start;
      
      // Check if hold time exceeds threshold
      if (hold_time >= HOLD_TIME_MS) {
        if (power_state) {
          // Power OFF sequence
          Serial.println("powerOFF"); // Notify ESP32 about power off
          digitalWrite(POWER_PIN, LOW);
          power_state = false;
          
          // Wait for button release before proceeding
          while (digitalRead(BTN_POWER) == LOW) {
            delay(10);
          }
        } else {
          // Power ON sequence
          digitalWrite(POWER_PIN, HIGH);
          power_state = true;
          Serial.println("powerON"); // Notify ESP32 about power on
          
          // Prevent instant turn-off
          delay(MIN_ON_TIME_MS);
          
          // Wait for button release
          while (digitalRead(BTN_POWER) == LOW) {
            delay(10);
          }
        }
      }
    }
  } else {
    // Button released
    button_was_pressed = false;
  }
}
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
 void loop() {
   // POLL BUTTONS
   handle_power_toggle();
   checkHomeBTN();
 
   // CHECK FOR ENABLE/DISABLE MSGs
   processESP32Message();
   
   // READ joysticks if enabled
   if (controller1Enabled) {
     checkControllerJoystick(1, 30);
   }
 
   if (controller2Enabled) {
     checkControllerJoystick(2, 30);
   }
 
   // CHECK PINCHANGE
   if (portB_dirty) {
     sendCommandFromFlags(portB_flags, 'B');
     portB_dirty = false;
   }
 
   if (portD_dirty) {
     sendCommandFromFlags(portD_flags, 'D');
     portD_dirty = false;
   }
 }

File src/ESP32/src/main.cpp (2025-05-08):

/**
 * @file main.cpp
 * @author Matt Krueger & Sage Marks
 * @brief ESP32 driver code
 * @version 0.1
 * @date May 7th, 2025
 * 
 * @copyright Copyright (c) 2025
 * 
 * This sketch serves as the state machine for the system, reading in new actions from the user over UART connected to IO of Arduino 
 * to perform an action on the current program selected. This is a proof of concept for our system as we developed this as part of 
 * ECE-3360 Embedded Systems course at the University of Iowa. Because of this, our code is not designed all too well. 
 * 
 * Currently Programmed: 
 * - EtchASketch: draw in colors using rotary dials like the original EtchASketch
 * - Pixel Art: displays slideshow of pixel art images
 * 
 * Further iterations will improve the modularity to more easily extend the system to whatever we want to display.
 * 
 */

#include <ESP32-HUB75-MatrixPanel-I2S-DMA.h>
#include "PixelArt/PixelArt.h"
#include "EtchASketch/ColorSelectScreen.h"
#include "EtchASketch/EtchASketch.h"

///////////////////////////////////////////////////////////////////////////////////////////////////////////////
// ------------------------------------------ Panel Configuration ------------------------------------------ //
///////////////////////////////////////////////////////////////////////////////////////////////////////////////
#define PANEL_WIDTH 64
#define PANEL_HEIGHT 64
#define PANELS_NUMBER 1

//////////////////////////////////////////////////////////////////////////////////////////////////////////////
// ------------------------------------------ UART Configuration ------------------------------------------ //
//////////////////////////////////////////////////////////////////////////////////////////////////////////////
#define RXD2 16
#define TXD2 17

// IMPORTANT: using serial communication channel 2 on ESP32. This is easiest to use with the HUB75E interface
HardwareSerial mySerial(2);


////////////////////////////////////////////////////////////////////////////////////////////////////////////
// ------------------------------------------ Global Variables ------------------------------------------ //
////////////////////////////////////////////////////////////////////////////////////////////////////////////
// matrix object
MatrixPanel_I2S_DMA* dma_display = nullptr;


// colors similar to example code in ESP32 HUB75... library examples. These are later defined for modular usage
uint16_t myBLACK;
uint16_t yellow, white, brown, green;

/////////////////////////////////////////////////////////////////////////////////////////////////////////
// ------------------------------------------ State Machine ------------------------------------------ //
/////////////////////////////////////////////////////////////////////////////////////////////////////////
// starting state
bool inEtchMode = false;
uint16_t selectedColor;

// currently supported menu items
const char* menuItems[] = { "Sketch", "Images" };
const int numMenuItems = 2;
int selectedIndex = 0;

// supported pages
enum ScreenState { HOME, COLOR_SELECT, EtchASketch, LOGO_DISPLAY };
ScreenState currentScreen = HOME;

/**
 * @brief draws arrow for menu selection
 * 
 * @param y column location to start the arrow
 */
void drawArrow(int y) {
  dma_display->fillRect(0, y, 6, 8, myBLACK); 
  dma_display->setCursor(0, y);
  dma_display->setTextColor(green);  
  dma_display->print(">");
}

/**
 * @brief draws the current home screen 
 * 
 * Redraws with current selection. Arrows depict the currently selected menu item.
 * 
 */
void drawHomeScreen() {
  dma_display->fillScreen(myBLACK);
  dma_display->setTextSize(1);
  dma_display->setTextWrap(false);
  

  // Navbar: 'Home'
  const char* line1 = "HOME";
  int len1 = strlen(line1);
  int charWidth = 6;
  int startX1 = (dma_display->width() - len1 * charWidth) / 2;
  dma_display->setCursor(startX1, 0);

  // alternating styling of home text
  for (int i = 0; i < len1; i++) {
    dma_display->setTextColor((i % 2 == 0) ? yellow : white);
    dma_display->print(line1[i]);
  }

  // navbar border
  dma_display->drawLine(0, 8, PANEL_WIDTH, 8, white);

  // options menu
  int startY = 10;
  for (int i = 0; i < numMenuItems; i++) {
    const char* label = menuItems[i];
    int len = strlen(label);
    int charWidth = 6;
    int textWidth = len * charWidth;
    int startX = (dma_display->width() - textWidth) / 2;

    // draw arrows with some padding. this is how we are depicting the item to be selected with the next click of 'Home'
    if (i == selectedIndex) {
        dma_display->fillRect(startX - 8, startY, 6, 8, myBLACK); // left arrow
        dma_display->setCursor(startX - 8, startY);
        dma_display->setTextColor(green);
        dma_display->print(">");

        dma_display->fillRect(startX + textWidth + 2, startY, 6, 8, myBLACK); // right arrow 
        dma_display->setCursor(startX + textWidth + 2, startY);
        dma_display->setTextColor(green);
        dma_display->print("<");
    }

    // draw the code with styling:
    // "Sketch" is rainbow
    // "Image" is yellow
    dma_display->setCursor(startX, startY);
    for (int j = 0; j < len; j++) {
        uint16_t color;
        if (strcmp(label, "Sketch") == 0) {
            uint16_t rainbowColors[] = {
                dma_display->color565(255, 0, 0),     // red
                dma_display->color565(255, 165, 0),   // orange
                dma_display->color565(255, 255, 0),   // yellow
                dma_display->color565(0, 255, 0),     // green
                dma_display->color565(0, 0, 255),     // blue
                dma_display->color565(75, 0, 130),    // indigo
                dma_display->color565(148, 0, 211)    // violet
            };
            color = rainbowColors[j % 7];
        } 
        else {
            color = yellow;
        }
        dma_display->setTextColor(color);
        dma_display->print(label[j]);
    }
    startY += 10;
  }
}
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
